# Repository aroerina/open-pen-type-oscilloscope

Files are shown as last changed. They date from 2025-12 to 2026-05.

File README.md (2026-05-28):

# open-pen-type-oscilloscope

ペンタイプオシロスコープ用の KiCad 基板設計データです。回路やスペックはDroidOscilloを踏襲しています。

このリポジトリには、回路図、PCB レイアウト、カスタムシンボル、カスタムフットプリント、3D モデル、製造用データを含みます。

Screenshot 2025-10-04 at 6 28 01 PM.

Screenshot 2025-10-04 at 6 28 49 PM

## 概要

- KiCad プロジェクト: `USB_Oscilloscope.kicad_pro`
- 回路図: `USB_Oscilloscope.kicad_sch`
- PCB レイアウト: `USB_Oscilloscope.kicad_pcb`

- カスタムライブラリ: `ps_lib/`

## 関連リポジトリ

- ファームウェア: https://github.com/aroerina/DroidOscillo-Firmaware
- Android ホストアプリ: https://github.com/aroerina/DroidOscillo-Android_host
- 基板リポジトリ: https://github.com/aroerina/DoroidOscillo-Board

## 公開データ

回路図やガーバーファイルは、以下の Release ページにあります。

- https://github.com/aroerina/open-pen-type-oscilloscope/releases/tag/rev2.0

## 注意事項

- ファームウェア書き込みテストはまだ行っていません。かなり投げやり状態です。
- 製造や実装を行う前に、回路図、PCB、部品表、製造データを必ず確認してください。

## ライセンス

このハードウェア設計データは CERN Open Hardware Licence Version 2 - Permissive（CERN-OHL-P）で公開されています。

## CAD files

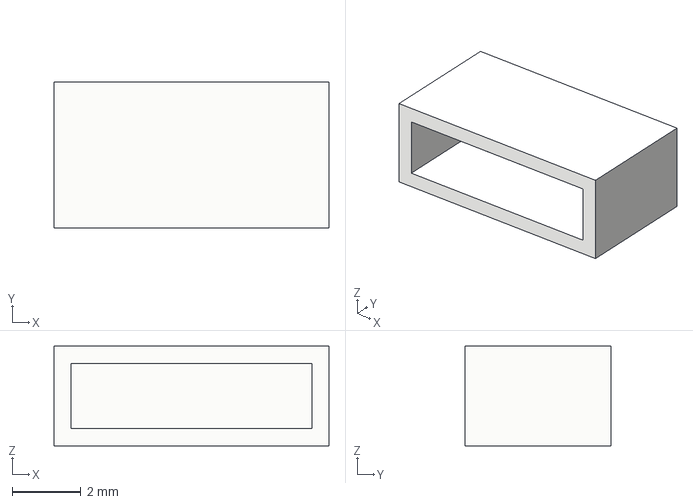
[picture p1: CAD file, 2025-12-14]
ps_lib/3dmodel/SM06B-SRSS-TB.step
8.00 x 4.25 x 2.90 mm

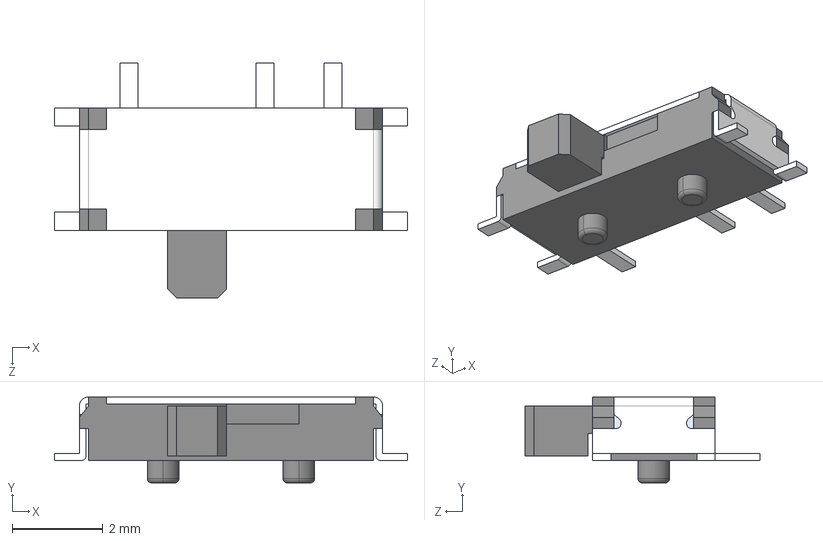
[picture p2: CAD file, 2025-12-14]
ps_lib/3dmodel/MSK12C02.stp
7.80 x 1.90 x 5.20 mm

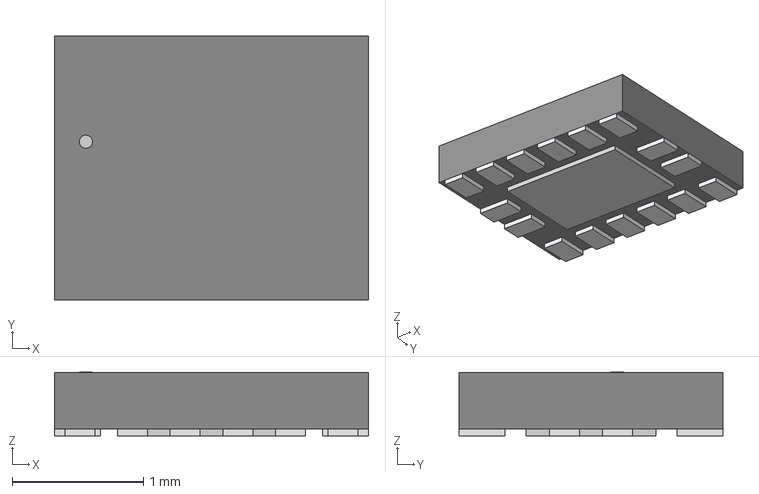
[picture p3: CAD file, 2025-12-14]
ps_lib/3dmodel/DHXQFN16_NEX.step
2.39 x 2.01 x 0.485 mm

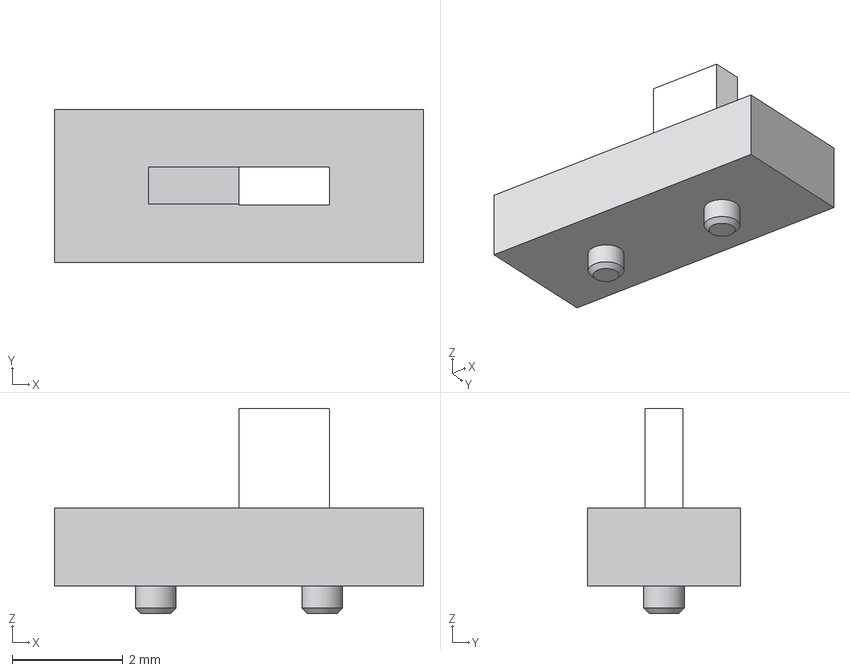
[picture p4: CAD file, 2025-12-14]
ps_lib/3dmodel/SHOU HAN MSS12C02LS-BB2.0.step
6.65 x 2.75 x 3.70 mm

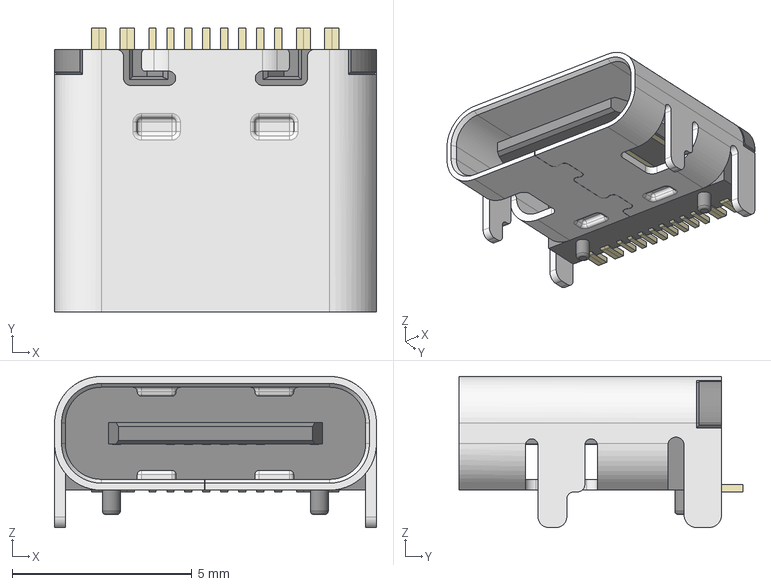
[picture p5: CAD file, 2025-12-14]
ps_lib/3dmodel/HRO_TYPE-C-31-M-12.step
8.95 x 7.90 x 4.20 mm

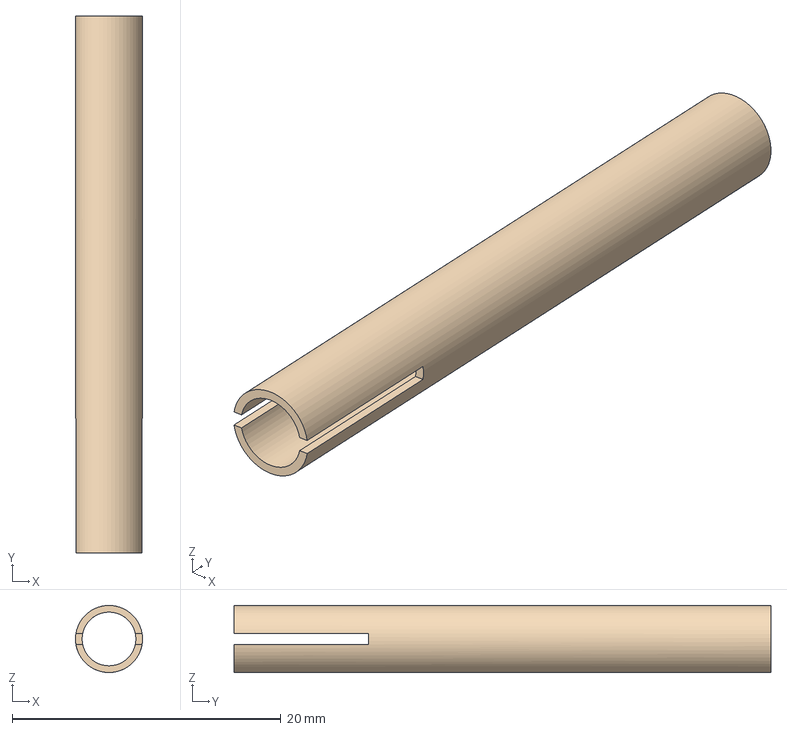
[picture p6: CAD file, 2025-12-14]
ps_lib/3dmodel/out5.0-in4.0 brass tube.step
5.00 x 40.0 x 5.00 mm

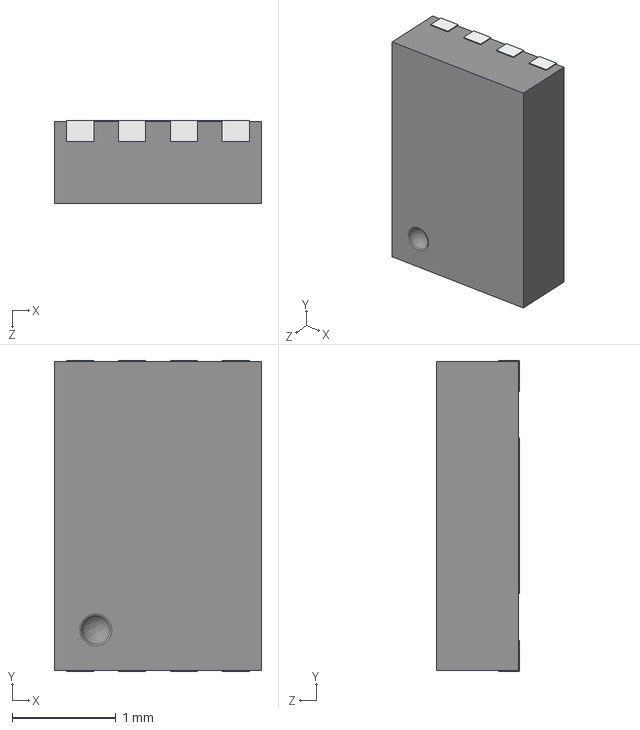
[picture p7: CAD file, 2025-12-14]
ps_lib/3dmodel/TDFN-8-1.STEP
2.00 x 3.00 x 0.8 mm

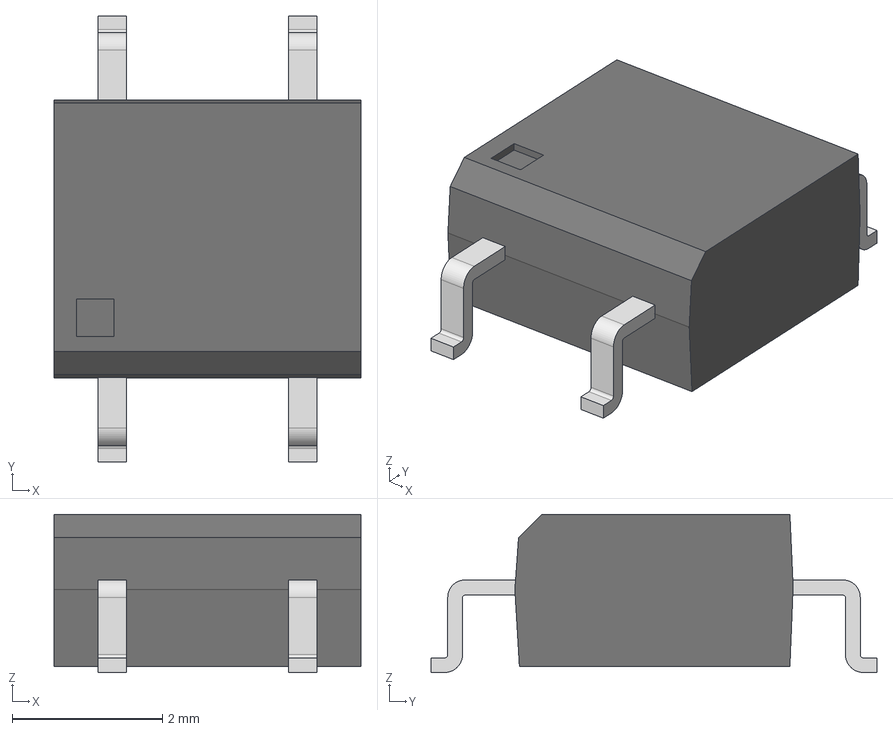
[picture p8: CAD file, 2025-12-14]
ps_lib/3dmodel/4-SOP v4.step
4.09 x 5.94 x 2.11 mm

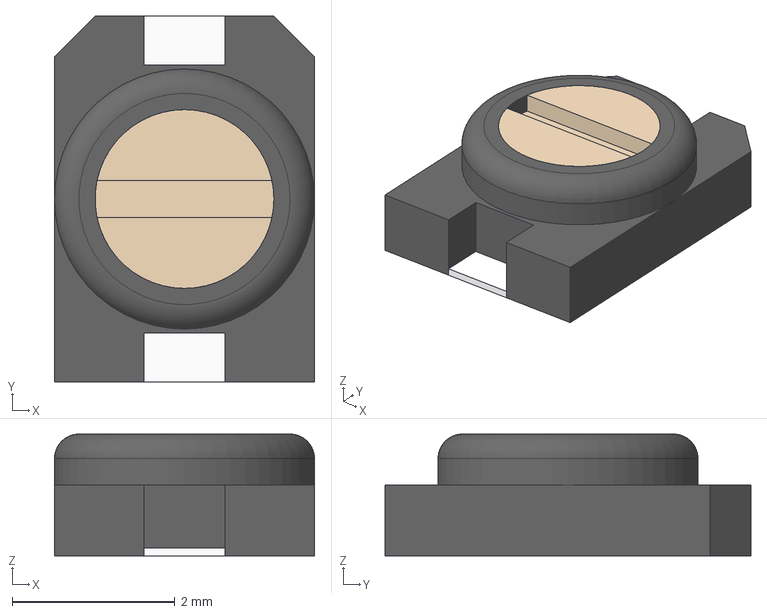
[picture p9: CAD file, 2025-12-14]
ps_lib/3dmodel/STC03M.step
3.20 x 4.50 x 1.50 mm

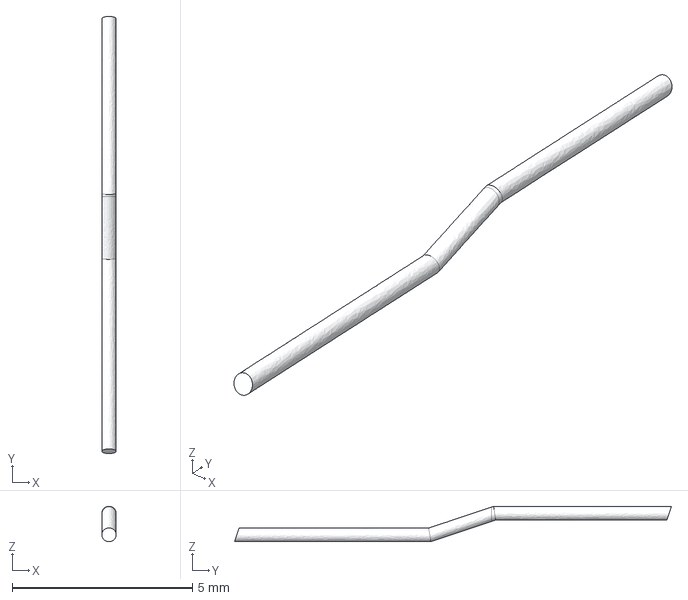
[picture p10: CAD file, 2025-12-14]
ps_lib/3dmodel/tip_wire.step
0.4 x 12.1 x 0.979 mm

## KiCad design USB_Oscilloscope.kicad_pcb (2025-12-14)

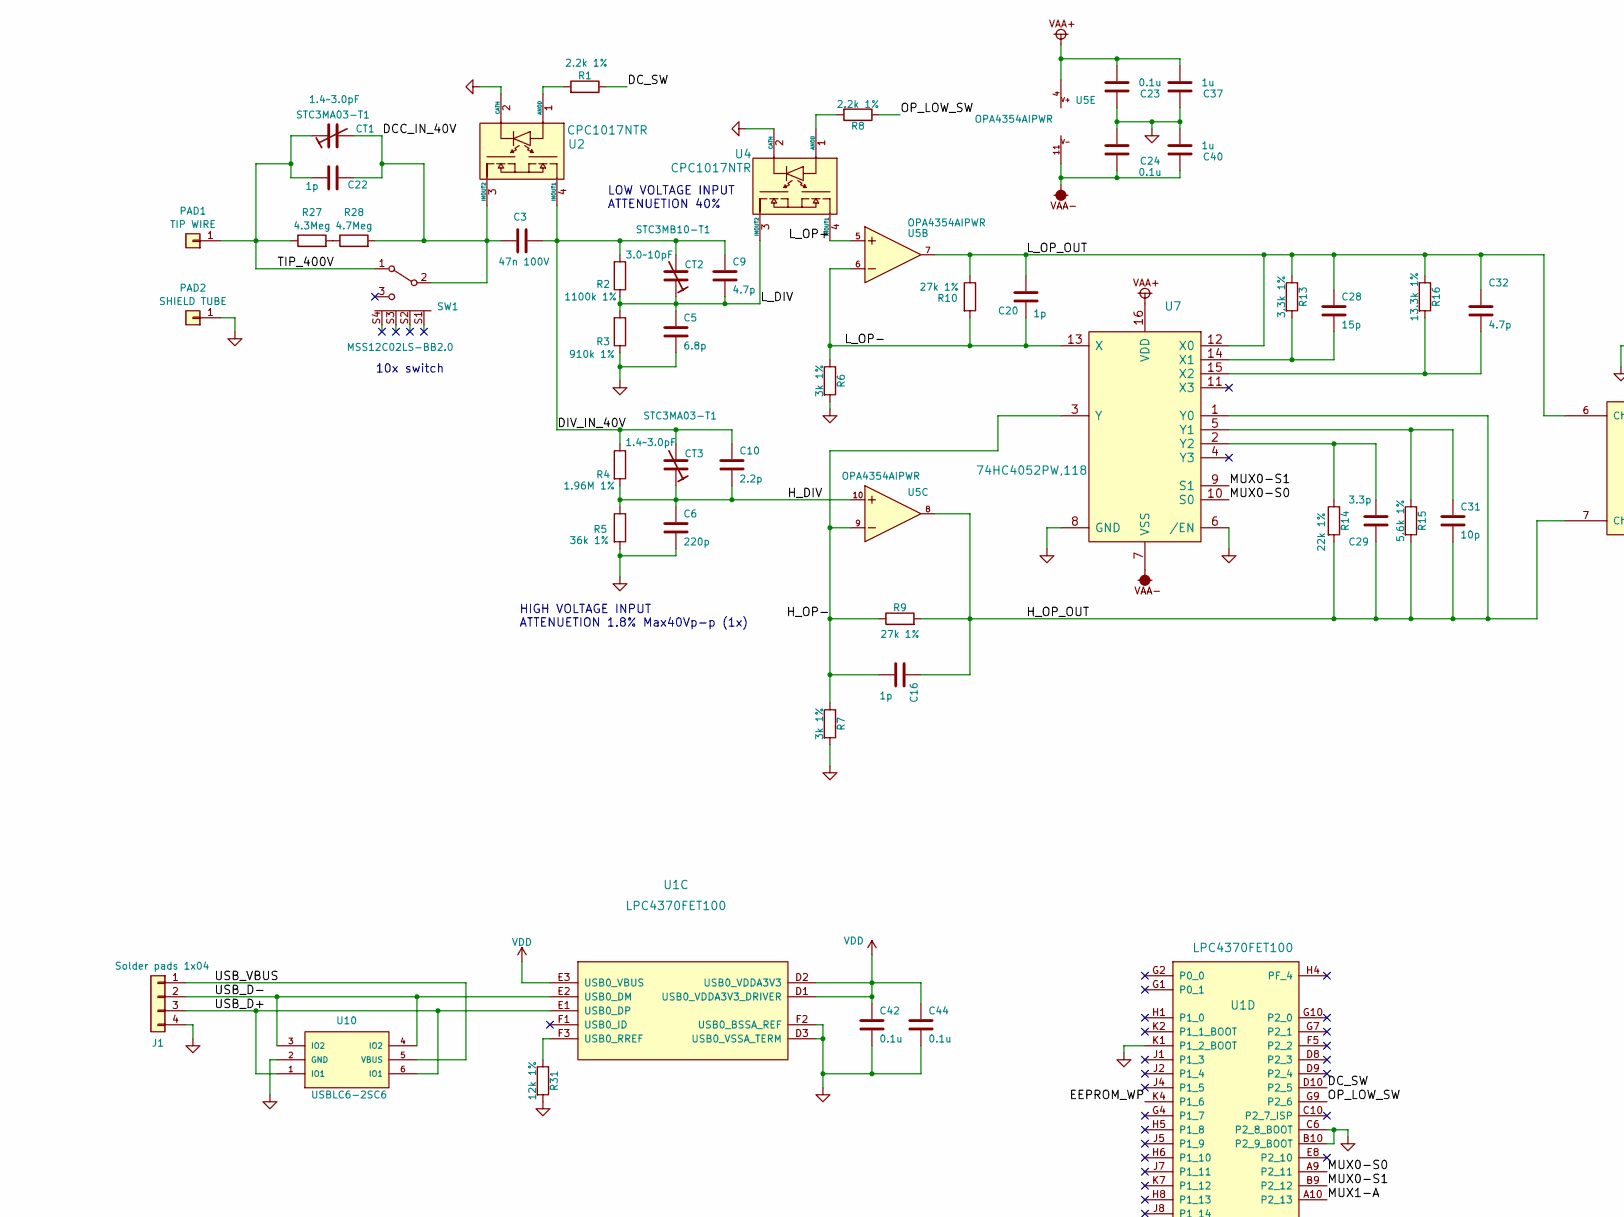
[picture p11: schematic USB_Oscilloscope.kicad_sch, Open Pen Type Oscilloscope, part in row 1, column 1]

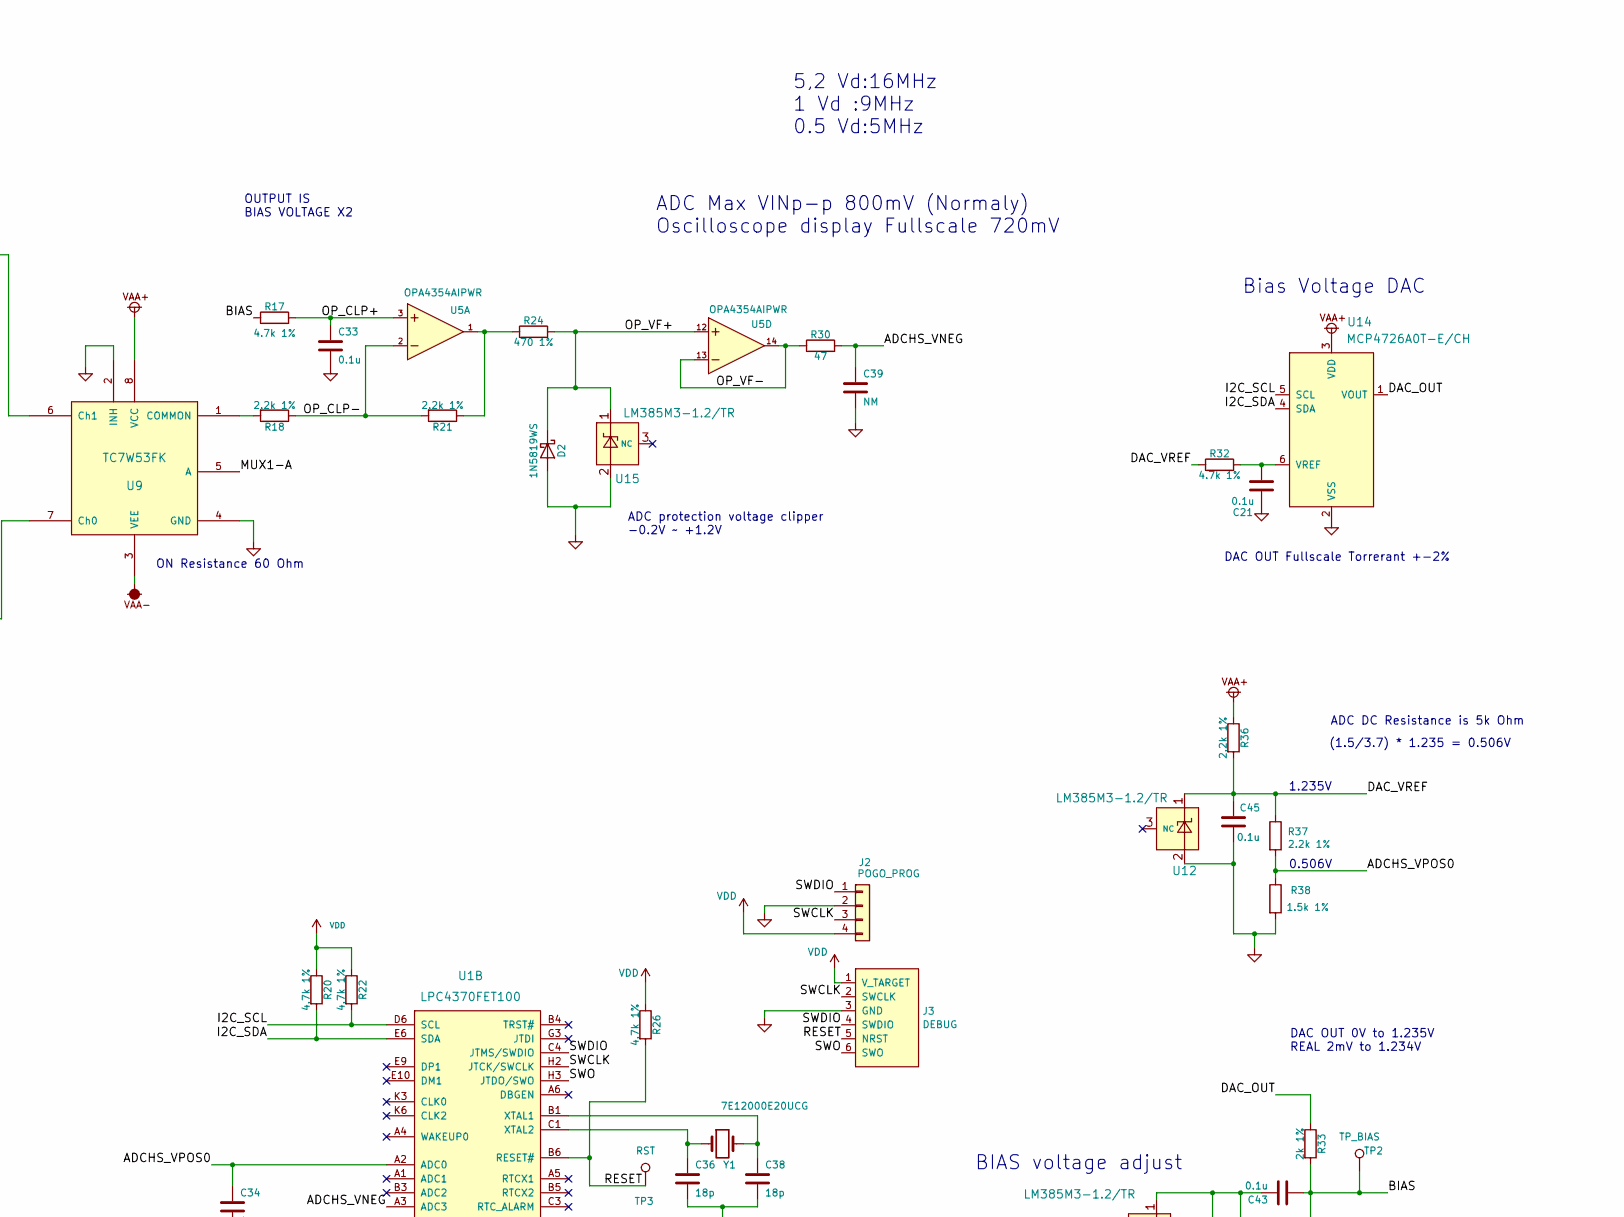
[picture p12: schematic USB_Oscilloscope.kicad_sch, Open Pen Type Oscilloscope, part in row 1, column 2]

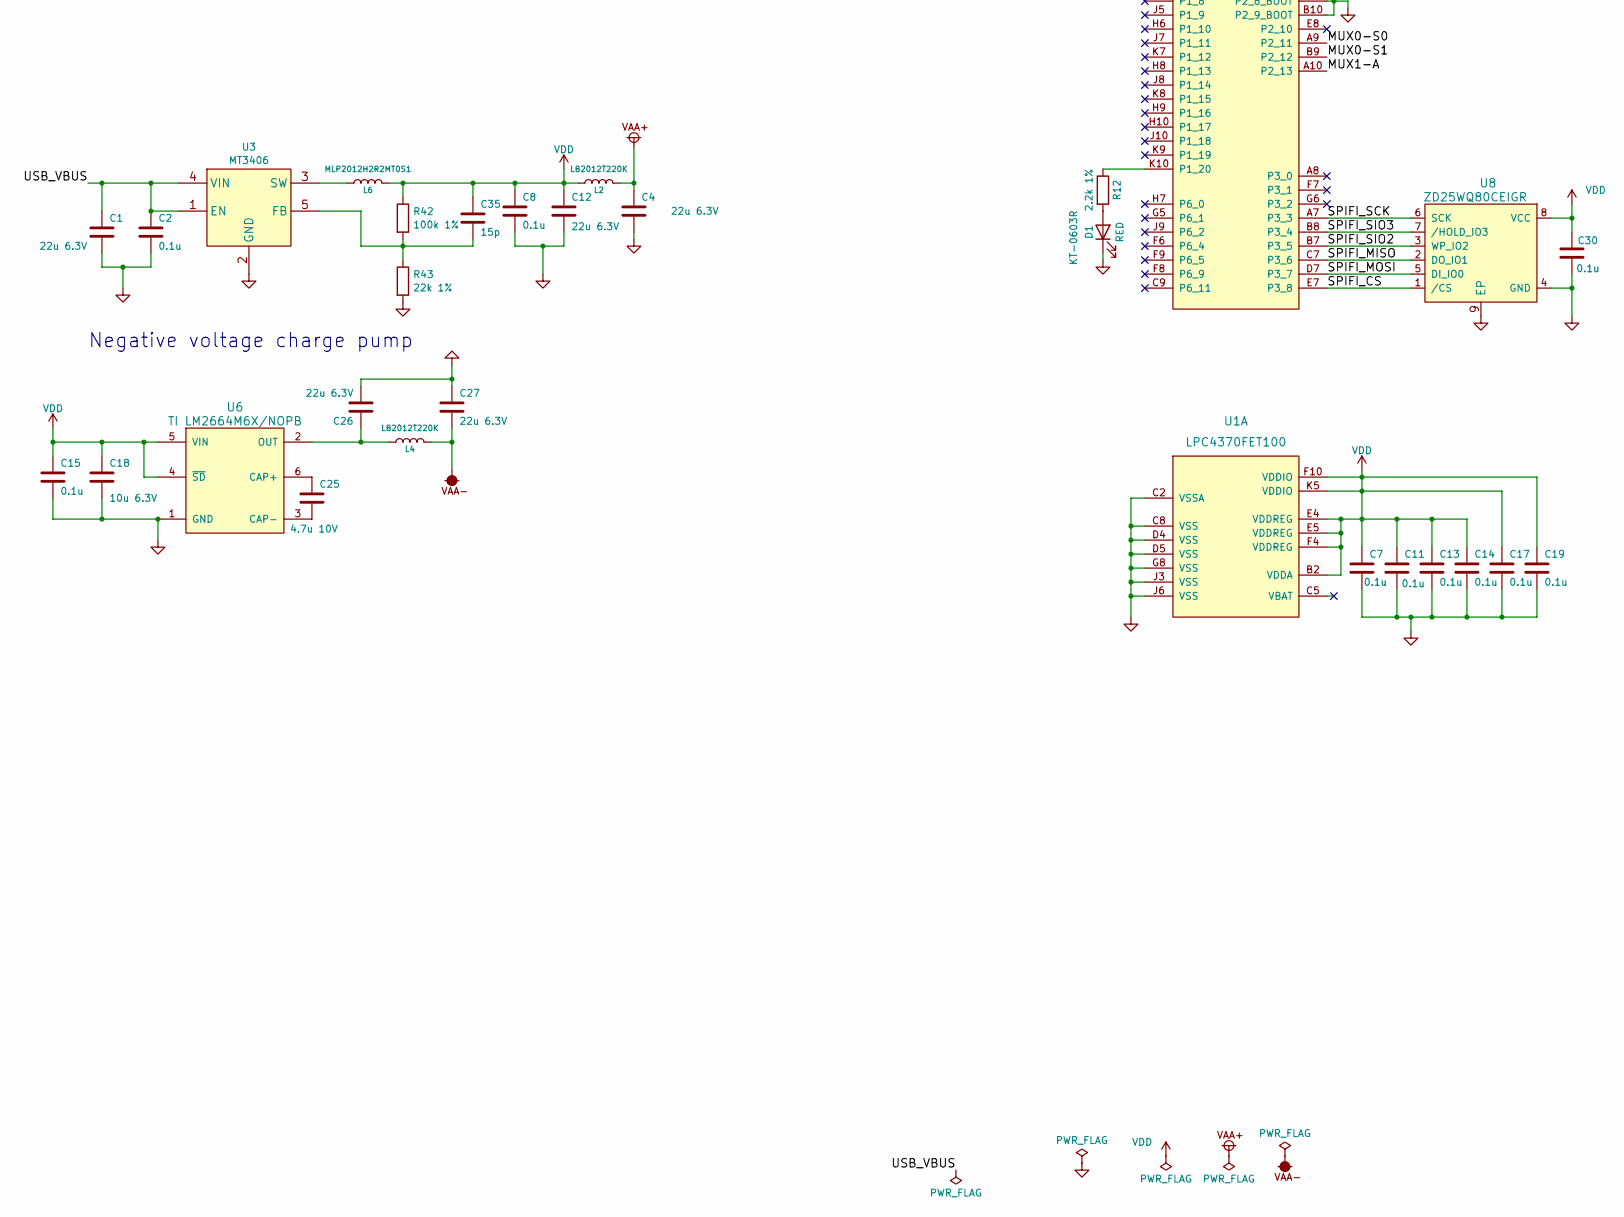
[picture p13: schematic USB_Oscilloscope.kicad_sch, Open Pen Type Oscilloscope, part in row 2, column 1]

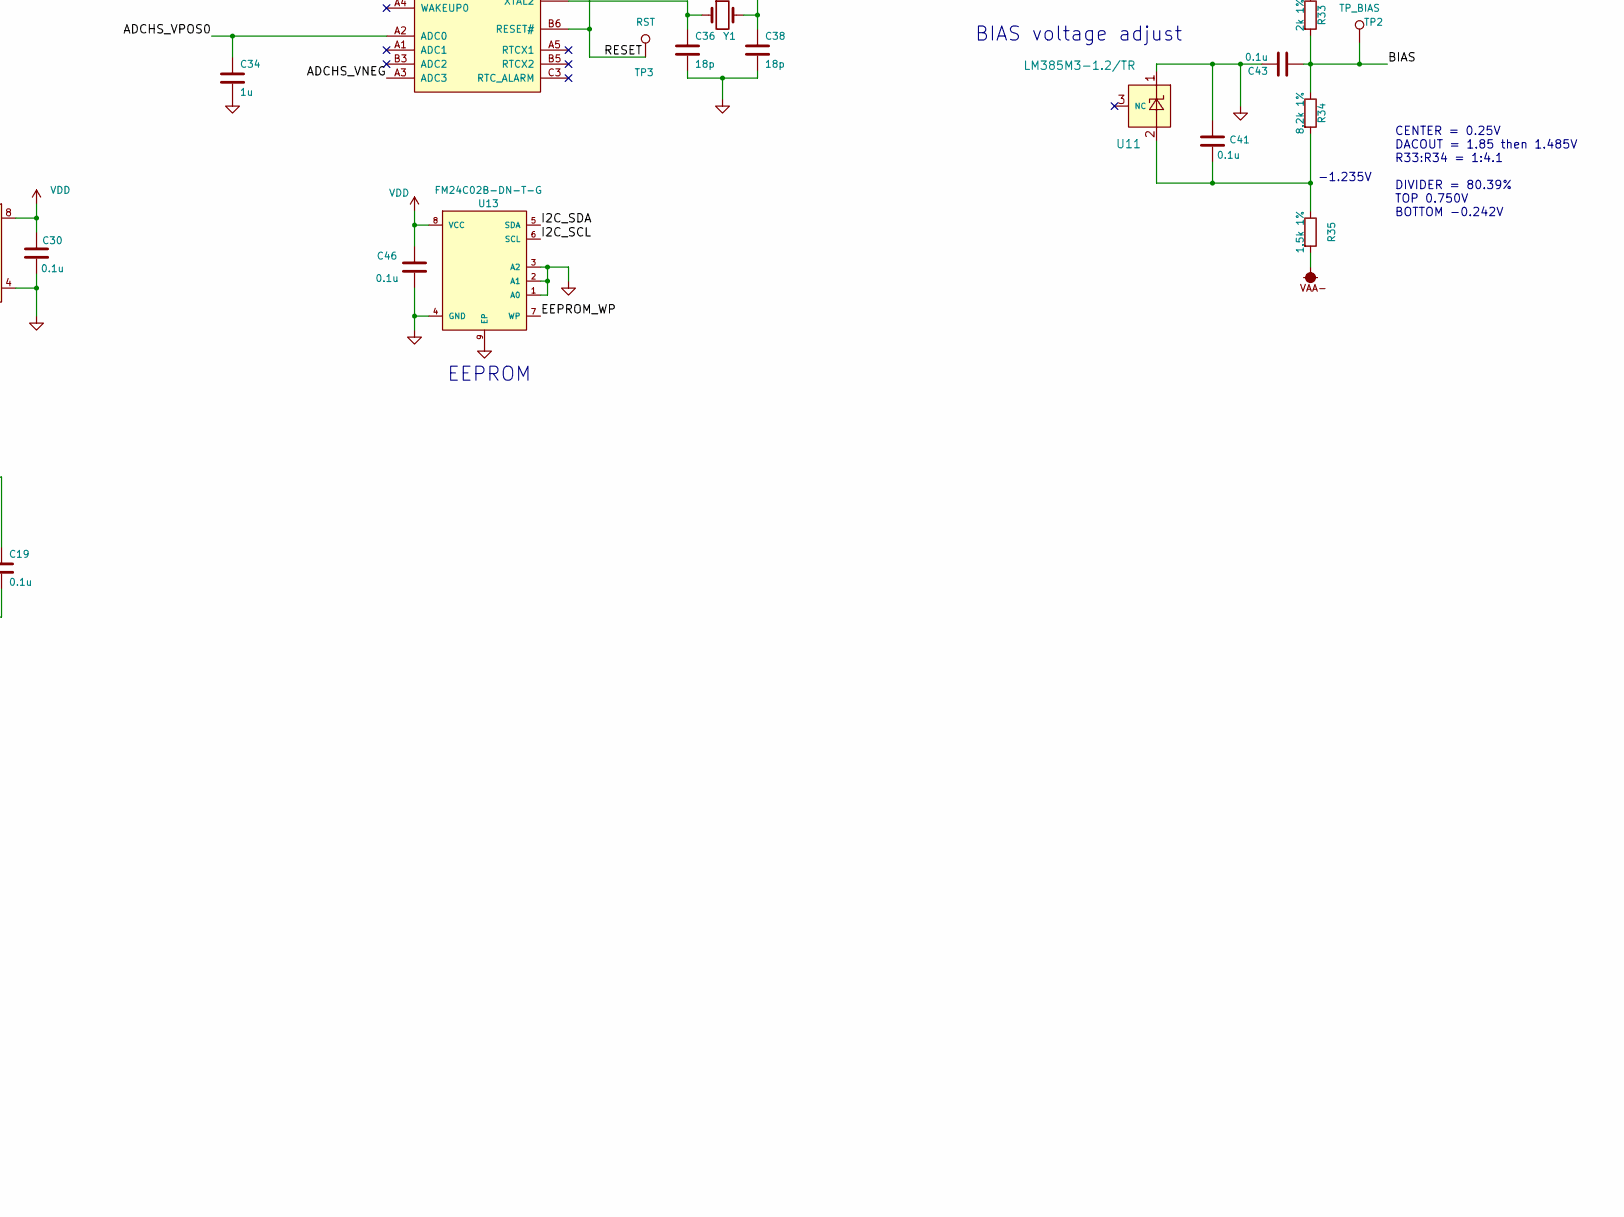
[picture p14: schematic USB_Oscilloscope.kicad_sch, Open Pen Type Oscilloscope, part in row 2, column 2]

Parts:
C1, C4, C12, C26, C27: 22u 6.3V; C_0603_1608Metric; LCSC C59461
C2, C7, C8, C11, C13, C14, C15, C17, C19, C21, C23, C24, C30, C33, C41, C42, C43, C44, C45, C46: 0.1u; C_0402_1005Metric; LCSC C1525
C3: 47n 100V; C_0805_2012Metric; LCSC C107126
C5: 6.8p; C_0402_1005Metric; LCSC C1576
C6: 220p; C_0402_1005Metric; LCSC C1530
C9, C32: 4.7p; C_0402_1005Metric; LCSC C1569
C10: 2.2p; C_0402_1005Metric; LCSC C1559
C16, C20: 1p; C_0402_1005Metric; LCSC C1550
C18: 10u 6.3V; C_0402_1005Metric; LCSC C15525
C22: 1p; C_0603_1608Metric; LCSC C3890240
C25: 4.7u 10V; C_0402_1005Metric; LCSC C23733
C28, C35: 15p; C_0402_1005Metric; LCSC C1548
C29: 3.3p; C_0402_1005Metric; LCSC C1565
C31: 10p; C_0402_1005Metric; LCSC C32949
C34, C37, C40: 1u; C_0402_1005Metric; LCSC C52923
C36, C38: 18p; C_0402_1005Metric
C39: NM; C_0402_1005Metric
CT1, CT3: STC3MA03-T1; SHEWA STC03M; LCSC C22468119
CT2: STC3MB10-T1; SHEWA STC03M; LCSC C22468121
D1: KT-0603R; LED_0603_1608Metric; LCSC C2286
D2: 1N5819WS; D_SOD-323; LCSC C191023
J1: Solder pads 1x04; 01x04_wire_pads_Pitch2.0
J2: POGO_PROG; PIN_HEADER_P1.27x4
J3: DEBUG; JST_SH_SM06B-SRSS-TB_1x06-1MP_P1.00mm_Horizontal; LCSC C7430448
L2, L4: LB2012T220K; L_0805_2012Metric; LCSC C223253
L6: MLP2012H2R2MT0S1; L_0805_2012Metric; LCSC C383369
PAD1: TIP WIRE; TIP_WIRE
PAD2: SHIELD TUBE; pipe-out5.0_in4.0_len40.0
R1, R8, R12, R18, R21, R36, R37: 2.2k 1%; R_0402_1005Metric; LCSC C25879
R2: 1100k 1%; R_0402_1005Metric; LCSC C133039
R3: 910k 1%; R_0402_1005Metric; LCSC C25800
R4: 1.96M 1%; R_0402_1005Metric; LCSC C477601
R5: 36k 1%; R_0402_1005Metric; LCSC C43676
R6, R7: 3k 1%; R_0402_1005Metric; LCSC C25784
R9, R10: 27k 1%; R_0402_1005Metric; LCSC C25771
R13: 3.3k 1%; R_0402_1005Metric; LCSC C25890
R14, R43: 22k 1%; R_0402_1005Metric; LCSC C25768
R15: 5.6k 1%; R_0402_1005Metric; LCSC C25908
R16: 13.3k 1%; R_0402_1005Metric; LCSC C122547
R17, R20, R22, R26, R32: 4.7k 1%; R_0402_1005Metric; LCSC C25900
R24: 470 1%; R_0402_1005Metric; LCSC C25117
R27: 4.3Meg; R_0805_2012Metric; LCSC C17668
R28: 4.7Meg; R_0805_2012Metric; LCSC C17674
R30: 47; R_0402_1005Metric; LCSC C25118
R31: 12k 1%; R_0402_1005Metric; LCSC C25752
R33: 2k 1%; R_0402_1005Metric; LCSC C4109
R34: 8.2k 1%; R_0402_1005Metric; LCSC C25924
R35, R38: 1.5k 1%; R_0402_1005Metric; LCSC C25867
R42: 100k 1%; R_0402_1005Metric; LCSC C25741
SW1: MSS12C02LS-BB2.0; LCSC C3008585
TP2: TP_BIAS; TestPoint_Pad_D1.0mm
TP3: RST; TestPoint_Pad_D1.0mm
U1: LPC4370FET100; TFBGA-100_8x8mm_Layout10x10_P0.8mm; LCSC C1020255
U2, U4: CPC1017NTR; CPC1017N; LCSC C81521
U3: MT3406; SOT-23-5; LCSC C22462728
U5: OPA4354AIPWR; TSSOP-14_4.4x5mm_P0.65mm; LCSC C527494
U6: TI LM2664M6X/NOPB; SOT-23-6; LCSC C108573
U7: 74HC4052PW,118; TSSOP-16_4.4x5mm_P0.65mm; LCSC C5646
U8: ZD25WQ80CEIGR; Winbond_USON-8-1EP_3x2mm_P0.5mm_EP0.2x1.6mm; LCSC C16197313
U9: TC7W53FK; VSSOP-8_2.3x2mm_P0.5mm; LCSC C146370
U10: USBLC6-2SC6; SOT-23-6; LCSC C7519
U11, U12, U15: LM385M3-1.2/TR; SOT-23-3; LCSC C507206
U13: FM24C02B-DN-T-G; TDFN-8-1EP_3x2mm_P0.5mm_EP1.4x1.4mm; LCSC C250843
U14: MCP4726A0T-E/CH; SOT-23-6; LCSC C191581
Y1: 7E12000E20UCG; Crystal_SMD_2520-4Pin_2.5x2.0mm; LCSC C252259

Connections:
/ADCHS_VNEG: C39.1, R30.2, U1.A3 (ADC3)
/ADCHS_VPOS0: C34.1, R37.2, R38.1, U1.A2 (ADC0)
/BIAS: C43.2, R17.1, R33.2, R34.1, TP2.1
/DAC_OUT: R33.1, U14.1 (VOUT)
/DAC_VREF: C45.1, R32.1, R36.2, R37.1, U12.1
/DCC_IN_40V: C3.1, C22.1, CT1.2, R28.2, SW1.2 (B), U2.3 (INOUT2)
/DC_SW: R1.1, U1.D10 (P2_5)
/DIV_IN_40V: C3.2, C9.1, C10.1, CT2.2, CT3.2, R2.2, R4.1, U2.4 (INOUT1)
/EEPROM_WP: U1.K4 (P1_6), U13.7 (WP)
/H_DIV: C6.1, C10.2, CT3.1, R4.2, R5.1, U5.10 (+IN)
/H_OP-: C16.2, R7.1, R9.1, U5.9 (-IN), U7.3 (Y)
/H_OP_OUT: C16.1, C29.2, C31.2, R9.2, R14.2, R15.2, U5.8 (OUT), U7.1 (Y0), U9.7 (Ch0)
/I2C_SCL: R22.2, U1.D6 (SCL), U13.6 (SCL), U14.5 (SCL)
/I2C_SDA: R20.2, U1.E6 (SDA), U13.5 (SDA), U14.4 (SDA)
/L_DIV: C5.1, C9.2, CT2.1, R2.1, R3.2, U4.3 (INOUT2)
/L_OP+: U4.4 (INOUT1), U5.5 (+IN)
/L_OP-: C20.1, R6.1, R10.2, U5.6 (-IN), U7.13 (X)
/L_OP_OUT: C20.2, C28.1, C32.1, R10.1, R13.1, R16.1, U5.7 (OUT), U7.12 (X0), U9.6 (Ch1)
/MUX0-S0: U1.A9 (P2_11), U7.10 (S0)
/MUX0-S1: U1.B9 (P2_12), U7.9 (S1)
/MUX1-A: U1.A10 (P2_13), U9.5 (A)
/OP_CLP+: C33.1, R17.2, U5.3 (+IN)
/OP_CLP-: R18.1, R21.2, U5.2 (-IN)
/OP_LOW_SW: R8.1, U1.G9 (P2_6)
/OP_VF+: D2.1 (K), R24.2, U5.12 (+IN), U15.1
/OP_VF-: R30.1, U5.13 (-IN), U5.14 (OUT)
/RESET: J3.5 (NRST), R26.2, TP3.1, U1.B6 (RESET#)
/SPIFI_CS: U1.E7 (P3_8), U8.1 (/CS)
/SPIFI_MISO: U1.C7 (P3_6), U8.2 (DO_IO1)
/SPIFI_MOSI: U1.D7 (P3_7), U8.5 (DI_IO0)
/SPIFI_SCK: U1.A7 (P3_3), U8.6 (SCK)
/SPIFI_SIO2: U1.B7 (P3_5), U8.3 (WP_IO2)
/SPIFI_SIO3: U1.B8 (P3_4), U8.7 (/HOLD_IO3)
/SWCLK: J2.3, J3.2 (SWCLK), U1.H2 (JTCK/SWCLK)
/SWDIO: J2.1, J3.4 (SWDIO), U1.C4 (JTMS/SWDIO)
/SWO: J3.6 (SWO), U1.H3 (JTDO/SWO)
/TIP_400V: C22.2, CT1.1, PAD1.1, R27.1, SW1.1 (A)
/USB_D+: J1.3, U1.E1 (USB0_DP), U10.1 (IO1), U10.6 (IO1)
/USB_D-: J1.2, U1.E2 (USB0_DM), U10.3 (IO2), U10.4 (IO2)
/USB_VBUS: C1.1, C2.1, J1.1, U3.1 (EN), U3.4 (VIN), U10.5 (VBUS)
GND: C1.2, C2.2, C4.2, C5.2, C6.2, C7.2, C8.2, C11.2, C12.2, C13.2, C14.2, C15.2, C17.2, C18.2, C19.2, C21.2, C23.2, C24.1, C26.2, C27.1, C30.2, C33.2, C34.2, C36.2, C37.2, C38.2, C39.2, C40.1, C41.2, C42.2, C43.1, C44.2, C45.2, C46.2, D1.1 (K), D2.2 (A), J1.4, J2.2, J3.3 (GND), PAD2.1, R3.1, R5.2, R6.2, R7.2, R31.2, R38.2, R43.2, U1.B10 (P2_9_BOOT), U1.C2 (VSSA), U1.C6 (P2_8_BOOT), U1.C8 (VSS), U1.D3 (USB0_VSSA_TERM), U1.D4 (VSS), U1.D5 (VSS), U1.F2 (USB0_BSSA_REF), U1.G8 (VSS), U1.J3 (VSS), U1.J6 (VSS), U1.K1 (P1_2_BOOT), U2.2 (CATH), U3.2 (GND), U4.2 (CATH), U6.1 (GND), U7.6 (/EN), U7.8 (GND), U8.4 (GND), U8.9 (EP), U9.2 (INH), U9.4 (GND), U10.2 (GND), U11.1, U12.2, U13.1 (A0), U13.2 (A1), U13.3 (A2), U13.4 (GND), U13.9 (EP), U14.2 (VSS), U15.2
unnamed: C41.1, R34.2, R35.1, U11.2
unnamed: D1.2 (A), R12.2
unnamed: R27.2, R28.1
unnamed: C38.1, U1.B1 (XTAL1), Y1.2
unnamed: C36.1, U1.C1 (XTAL2), Y1.1
unnamed: R31.1, U1.F3 (USB0_RREF)
unnamed: R12.1, U1.K10 (P1_20)
unnamed: R1.2, U2.1 (ANOD)
unnamed: C35.2, R42.2, R43.1, U3.5 (FB)
unnamed: L6.1, U3.3 (SW)
unnamed: R8.2, U4.1 (ANOD)
unnamed: R21.1, R24.1, U5.1 (OUT)
unnamed: C25.1, U6.6 (CAP+)
unnamed: C25.2, U6.3 (CAP-)
unnamed: C26.1, L4.1, U6.2 (OUT)
unnamed: C28.2, R13.2, U7.14 (X1)
unnamed: C32.2, R16.2, U7.15 (X2)
unnamed: C31.1, R15.1, U7.5 (Y1)
unnamed: C29.1, R14.1, U7.2 (Y2)
unnamed: R18.2, U9.1 (COMMON)
unnamed: C21.1, R32.2, U14.6 (VREF)
VDD: C7.1, C8.1, C11.1, C12.1, C13.1, C14.1, C15.1, C17.1, C18.1, C19.1, C30.1, C35.1, C42.1, C44.1, C46.1, J2.4, J3.1 (V_TARGET), L2.1, L6.2, R20.1, R22.1, R26.1, R42.1, U1.B2 (VDDA), U1.D1 (USB0_VDDA3V3_DRIVER), U1.D2 (USB0_VDDA3V3), U1.E3 (USB0_VBUS), U1.E4 (VDDREG), U1.E5 (VDDREG), U1.F4 (VDDREG), U1.F10 (VDDIO), U1.K5 (VDDIO), U6.4 (~SD), U6.5 (VIN), U8.8 (VCC), U13.8 (VCC)
alt_VAA+: C4.1, C23.1, C37.1, L2.2, R36.1, U5.4 (V+), U7.16 (VDD), U9.8 (VCC), U14.3 (VDD)
alt_VAA-: C24.2, C27.2, C40.2, L4.2, R35.2, U5.11 (V-), U7.7 (VSS), U9.3 (VEE)

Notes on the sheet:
HIGH VOLTAGE INPUT ATTENUETION 1.8% Max40Vp-p (1x)
Bias Voltage DAC
EEPROM
-1.235V
DAC OUT 0V to 1.235V REAL 2mV to 1.234V
10x switch
0.506V
CENTER = 0.25V DACOUT = 1.85 then 1.485V R33:R34 = 1:4.1 DIVIDER = 80.39% TOP 0.750V BOTTOM -0.242V
LOW VOLTAGE INPUT ATTENUETION 40%
5,2 Vd:16MHz 1 Vd :9MHz 0.5 Vd:5MHz
ADC DC Resistance is 5k Ohm
Negative voltage charge pump
ON Resistance 60 Ohm
OUTPUT IS BIAS VOLTAGE X2
ADC protection voltage clipper -0.2V ~ +1.2V
1.235V
(1.5/3.7) * 1.235 = 0.506V
ADC Max VINp-p 800mV (Normaly) Oscilloscope display Fullscale 720mV
DAC OUT Fullscale Torrerant +-2%
BIAS voltage adjust

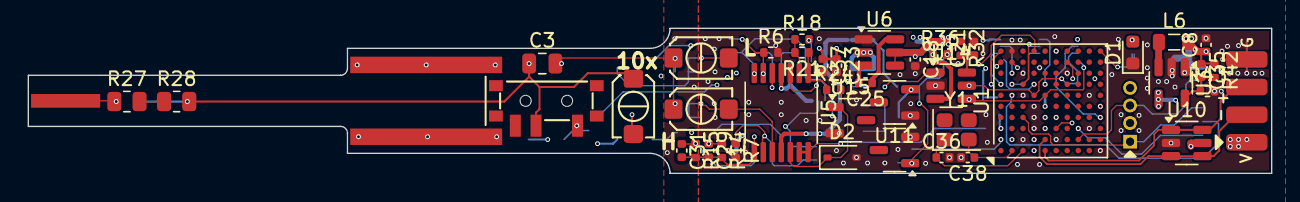
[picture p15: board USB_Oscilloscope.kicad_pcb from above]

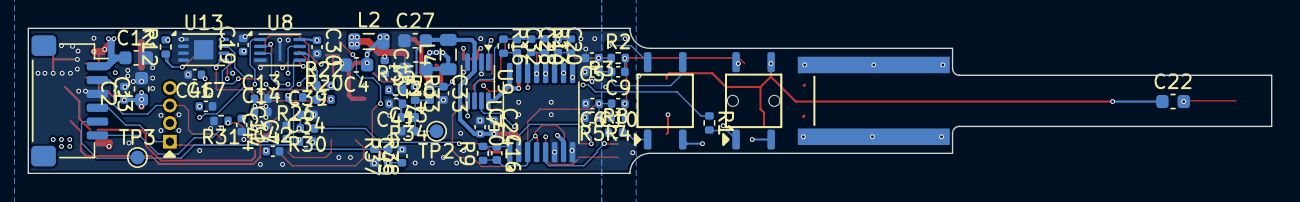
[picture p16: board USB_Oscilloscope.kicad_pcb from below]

Board: 4 copper layers, 90.0 x 10.5 mm, 113 parts (67 on the bottom side), 65 nets.

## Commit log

2025-09-18 回路図 DRC pass
    [Android_Oscilloscope-2025-09-13-16-39-59.sch, Android_Oscilloscope.kicad_pcb, Android_Oscilloscope.kicad_sch]
2025-09-22 プロジェクト名変更
    [Android_Oscilloscope.kicad_pcb, USB_Oscilloscope-2025-09-13-16-39-59.sch, USB_Oscilloscope-2025-09-18-20-48-20.sch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]
2025-12-14 ペン型オシロに変更
    [4-SOP v4.step, DHXQFN16_NEX.step, HRO_TYPE-C-31-M-12.step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]
2025-12-14 古い回路図を削除
2025-12-14 gabarフォルダを削除
    [USB_Oscilloscope-B.Cu.gbl, USB_Oscilloscope-B.Mask.gbs, USB_Oscilloscope-B.SilkS.gbo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]
2026-05-28 readme.mdを作成
2026-05-28 画像を追加
